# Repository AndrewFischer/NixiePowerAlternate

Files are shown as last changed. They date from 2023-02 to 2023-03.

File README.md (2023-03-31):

# NixiePowerAlternate
A regulated power supply for devices with a Nixie tube display.  
Vin is 9 to 14VDC.  Maximum input voltage is 16.5V. 
Outputs are 175VDC, 5VDC and 3.3VDC.<br>
MAX1771 maximum input is 16.5V which sets the upper limit on Vin.
TPS5430 and MAX1771 are inexpensive parts with reasonable performace. There are newer parts with better specs. Most are currently unavailable or beyond my ability to solder.
The TPS5430 is sensitive to choice of output capacitor. See the datasheet and application notes if you stray from the BOM.
#### Rev 0.1 Changes
* Improve HV boost regulator circuit.
* Correct footprint errors in Rev. 0. 
* Replace linear 5.0V regulator with a TPS5430 buck regulator.  Power the 3.3V regulator from the 5V supply. 

### Disclaimers and warnings
:exclamation: Danger of electric shock. 175Volts DC is present on this board.<br>
The files embodied in this repository are provided to you "as-is" and without warranty of any kind, express, implied or otherwise, including without limitation, any warranty of fitness for a particular purpose. See section 5 of the license.<br>
**This project is untested**.<br>
### License
[cc-by-nc 4.0](LICENSE.md)

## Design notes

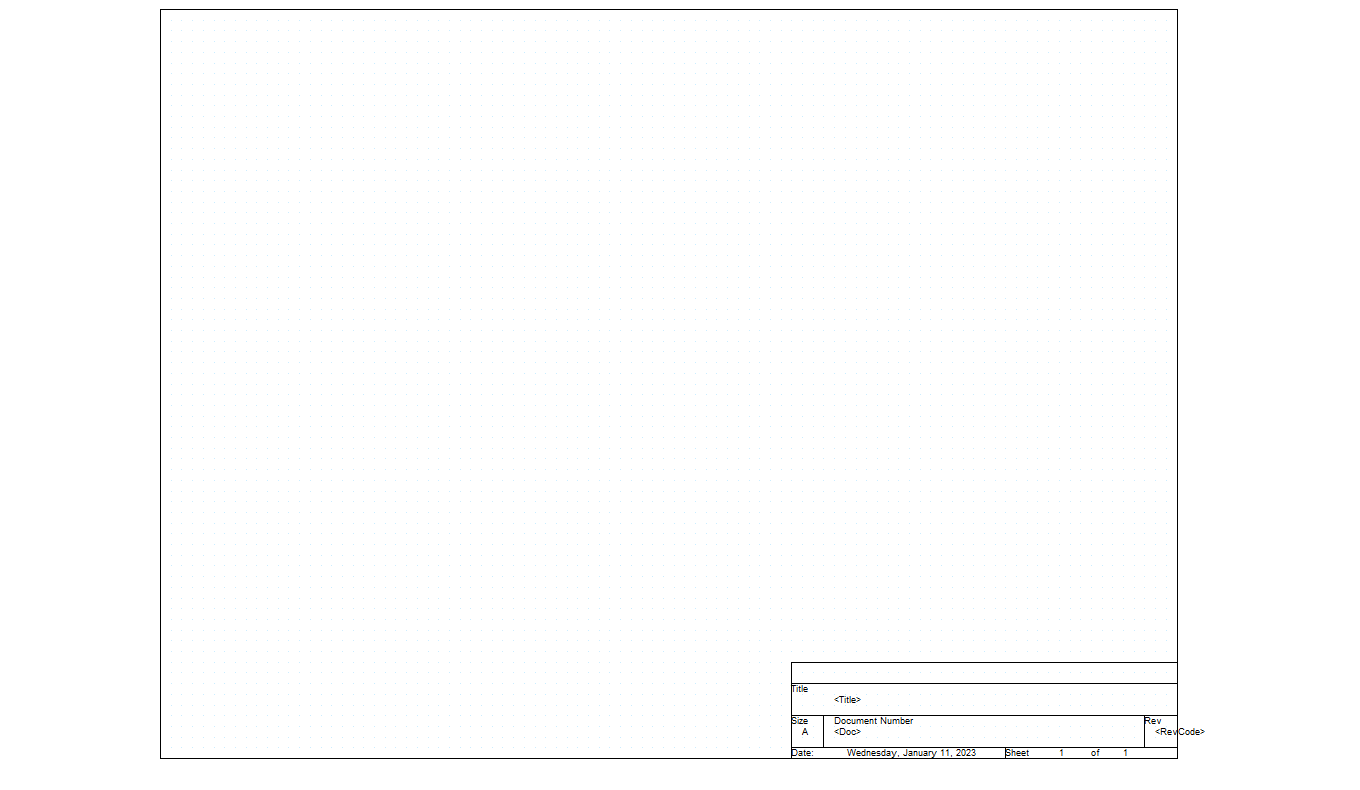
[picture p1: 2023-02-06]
NIXIEPOWERPSPICE.png

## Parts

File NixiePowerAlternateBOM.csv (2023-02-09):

Comment | Designator | Footprint | LCSC
4.7uF | C12,C13,C14 | Capacitor_SMD:C_1206_3216Metric_Pad1.33x1.80mm_HandSolder | C77094
100nF | C2,C5 | Capacitor_SMD:C_0805_2012Metric | C28233
47pF | C4 | Capacitor_SMD:C_1206_3216Metric_Pad1.33x1.80mm_HandSolder | C113890
1uF | C6 | Capacitor_SMD:C_0805_2012Metric_Pad1.18x1.45mm_HandSolder | C28323
100uF | C7,C9,C10,C11 | Capacitor_Tantalum_SMD:CP_EIA-3528-21_Kemet-B_Pad1.50x2.35mm_HandSolder | C16133
10nF | C8 | Capacitor_SMD:C_0805_2012Metric_Pad1.18x1.45mm_HandSolder | C1710
ES2F | D1 | Diode_SMD:D_SMB | C145321
SS34 | D2 | Diode_SMD:D_SMA_Handsoldering | C8678
~ | Q1 | Package_TO_SOT_SMD:TO-263-2 | C39238
1.18M | R1 | Resistor_SMD:R_1206_3216Metric_Pad1.30x1.75mm_HandSolder | C422598
0.05 | R2 | Resistor_SMD:R_1206_3216Metric_Pad1.30x1.75mm_HandSolder | C149662
10K | R3,R4 | Resistor_SMD:R_0805_2012Metric_Pad1.20x1.40mm_HandSolder | C17828
3.24K | R5 | Resistor_SMD:R_0805_2012Metric_Pad1.20x1.40mm_HandSolder | C245320
MAX1771ESA | U1 | Package_SO:SO-8_3.9x4.9mm_P1.27mm | C407903
AMS1117-3.3 | U2 | Package_TO_SOT_SMD:SOT-223-3_TabPin2 | C6186
TPS5430DDA | U3 | Package_SO:TI_SO-PowerPAD-8_ThermalVias | C9864

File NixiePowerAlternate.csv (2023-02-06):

Comment | Designator | Footprint | LCSC
100nF | C2,C3 | Capacitor_SMD:C_0805_2012Metric | C28233
1uF | C5,C6 | Capacitor_SMD:C_0805_2012Metric_Pad1.18x1.45mm_HandSolder | C28323
10uF | C7,C8 | Capacitor_Tantalum_SMD:CP_EIA-3216-18_Kemet-A | C7171
~ | D1 | Diode_SMD:D_SMB | C145321
~ | Q1 | Package_TO_SOT_SMD:TO-263-2 | C39238
0.05 | R1 | Resistor_SMD:R_1206_3216Metric_Pad1.30x1.75mm_HandSolder | C149662
1.2M | R2 | Resistor_SMD:R_1206_3216Metric_Pad1.30x1.75mm_HandSolder | C22107
6.8K | R3 | Resistor_SMD:R_0805_2012Metric_Pad1.20x1.40mm_HandSolder | C17772
AMS1117-5.0 | U1 | Package_TO_SOT_SMD:SOT-223-3_TabPin2 | C6187
MAX1771ESA | U2 | Package_SO:SO-8_3.9x4.9mm_P1.27mm | C407903
AMS1117-3.3 | U3 | Package_TO_SOT_SMD:SOT-223-3_TabPin2 | C6186

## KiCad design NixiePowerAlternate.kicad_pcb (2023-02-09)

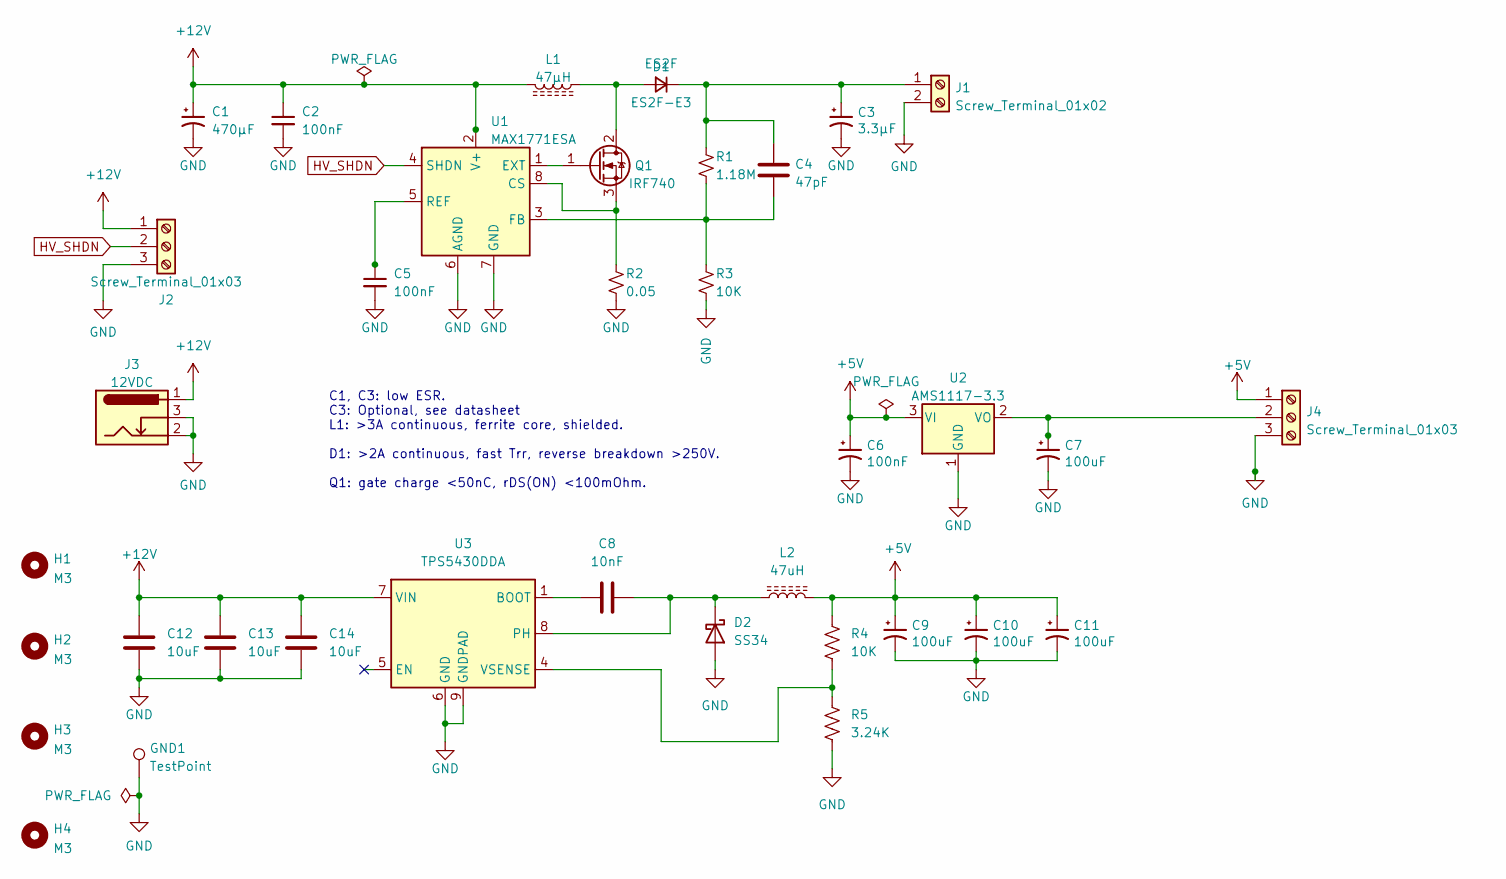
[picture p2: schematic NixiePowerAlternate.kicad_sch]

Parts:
C1: 470µF; CP_Radial_D10.0mm_P5.00mm; MPN UPW1V471MPD
C2, C5: 100nF; C_0805_2012Metric; Part# CL21B104KCFNNNE; LCSC C28233
C3: 3.3µF; CP_Radial_D10.0mm_P5.00mm; Part# UPW2G3R3MPD
C4: 47pF; C_1206_3216Metric_Pad1.33x1.80mm_HandSolder; MPN CC1206JRNPOBBN470; LCSC C113890
C6: 100nF; C_0805_2012Metric_Pad1.18x1.45mm_HandSolder; MPN CL21B104KBFNNNE; LCSC C28233
C7, C9, C10, C11: 100uF; CP_EIA-3528-21_Kemet-B_Pad1.50x2.35mm_HandSolder; MPN TAJB107K006RNJ; LCSC C16133
C8: 10nF; C_0805_2012Metric_Pad1.18x1.45mm_HandSolder; MPN CL21B103KBANNNC; LCSC C1710
C12, C13, C14: 10uF; C_1206_3216Metric_Pad1.33x1.80mm_HandSolder; MPN CL31A226KAHNNNE; LCSC C12891
D1: ES2F; D_SMB; MPN ES2F-E3; LCSC C145321
D2: SS34; D_SMA_Handsoldering; MPN SS34; LCSC C8678
GND1: TestPoint; TestPoint_THTPad_D4.0mm_Drill2.0mm
H1, H2, H3, H4: M3; MountingHole_3.2mm_M3
J1: Screw_Terminal_01x02; TerminalBlock_Phoenix_MKDS-1,5-2-5.08_1x02_P5.08mm_Horizont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
J2, J4: Screw_Terminal_01x03; TerminalBlock_Phoenix_MKDS-1,5-3-5.08_1x03_P5.08mm_Horizont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
J3: 12VDC; BarrelJack_RS_805-1696
L1: 47µH; L_CoilCraft_MSS1210; MPN MSS1210H-473ME
L2: 47uH; L_CoilCraft_MSS1048; MPN MSS1048-473MLB
Q1: TO-263-2; MPN IRF740; LCSC C39238
R1: 1.18M; R_1206_3216Metric_Pad1.30x1.75mm_HandSolder; Part# 1206W4F1184T5E; LCSC C422598
R2: 0.05; R_1206_3216Metric_Pad1.30x1.75mm_HandSolder; MPN CR1206FR050P05R; LCSC C149662
R3, R4: 10K; R_0805_2012Metric_Pad1.20x1.40mm_HandSolder; LCSC C17828
R5: 3.24K; R_0805_2012Metric_Pad1.20x1.40mm_HandSolder; MPN CR0805F3K24P05Z; LCSC C245320
U1: MAX1771ESA; SO-8_3.9x4.9mm_P1.27mm; LCSC C407903
U2: AMS1117-3.3; SOT-223-3_TabPin2; LCSC C6186
U3: TPS5430DDA; TI_SO-PowerPAD-8_ThermalVias; LCSC C9864

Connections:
+5V: C6.1, C9.1, C10.1, C11.1, J4.1, L2.2, R4.1, U2.3 (VI)
+12V: C1.1, C2.1, C12.1, C13.1, C14.1, J2.1, J3.1, L1.2, U1.2 (V+), U3.7 (VIN)
GND: C1.2, C2.2, C3.2, C5.2, C6.2, C7.2, C9.2, C10.2, C11.2, C12.2, C13.2, C14.2, D2.2 (A), GND1.1, J1.2, J2.3, J3.2, J3.3, J4.3, R2.2, R3.2, R5.2, U1.6 (AGND), U1.7 (GND), U2.1 (GND), U3.6 (GND), U3.9 (GNDPAD)
HV_SHDN: J2.2, U1.4 (SHDN)
unnamed: C3.1, C4.1, D1.1 (K), J1.1, R1.1
unnamed: C4.2, R1.2, R3.1, U1.3 (FB)
unnamed: C5.1, U1.5 (REF)
unnamed: C7.1, J4.2, U2.2 (VO)
unnamed: C8.1, U3.1 (BOOT)
unnamed: C8.2, D2.1 (K), L2.1, U3.8 (PH)
unnamed: D1.2 (A), L1.1, Q1.2 (D)
unnamed: Q1.1 (G), U1.1 (EXT)
unnamed: Q1.3 (S), R2.1, U1.8 (CS)
unnamed: R4.2, R5.1, U3.4 (VSENSE)

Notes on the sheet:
C1, C3: low ESR. C3: Optional, see datasheet L1: >3A continuous, ferrite core, shielded. D1: >2A continuous, fast Trr, reverse breakdown >250V. Q1: gate charge <50nC, rDS(ON) <100mOhm.

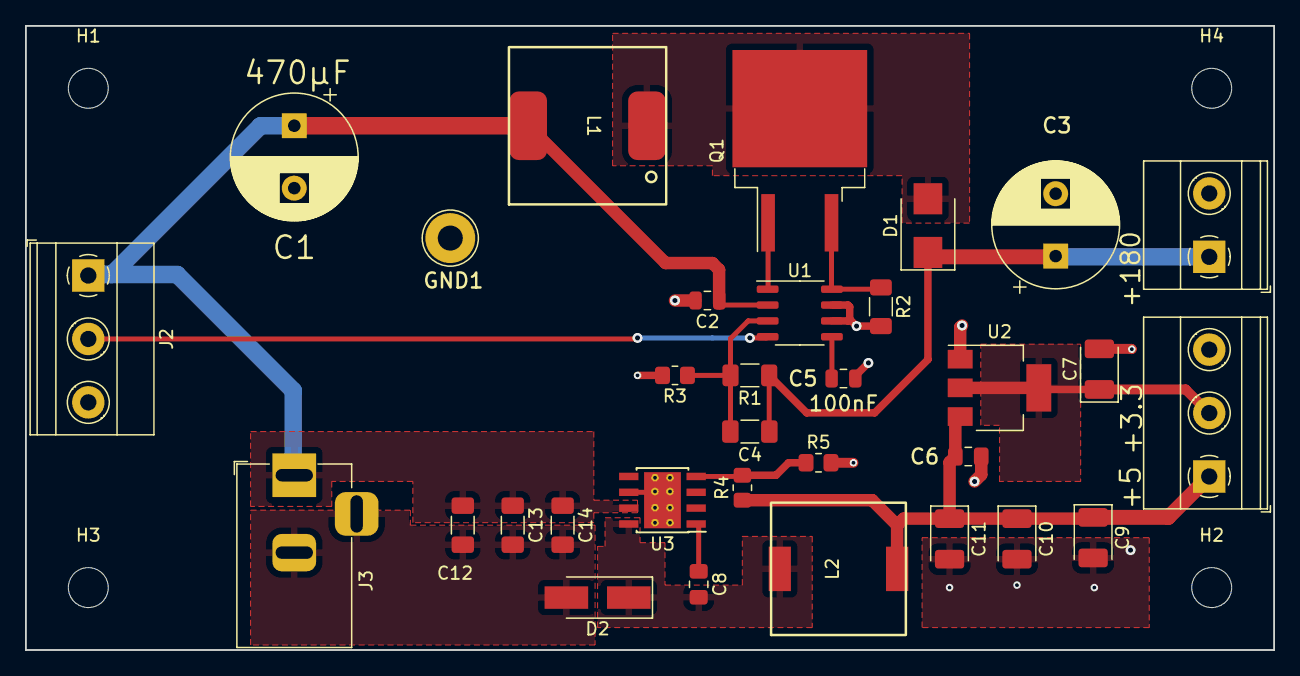
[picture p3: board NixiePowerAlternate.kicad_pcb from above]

Board: 2 copper layers, 100.0 x 50.0 mm, 36 parts (0 on the bottom side), 14 nets.

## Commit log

2023-02-06 Add files via upload
    Initial commit for Rev 0.
    Rev 0 has issues and should not be used as is.
    [DESIGN1.DSN, NIXIEPOWERPSPICE.DSN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]
2023-02-07 Add files via upload
    Checked L1 and Q1 against recommendations in the datasheet. Decided to keep as is. The MOSFET is fine. L1 should be too and it is rated for 400V.
    Added feed forward capacitor C9, 47pF in parallel with R2. The datasheet suggests values between 47pF and 220pF, using the lowest that insures stability. The design is stable in PSPICE without the cap. In practice it may be optional.
    Updated the PCB with the parts changes and fixed a layout error from Rev 0.
    [NixiePowerAlternate.kicad_pcb, NixiePowerAlternate.kicad_sch]
2023-02-08 Add files via upload
    Replace linear 5V regulator with a buck SMPS in the schematic.
    Begin adding MSS1048 footprint
    [NixiePowerAlternate.kicad_sch]
2023-02-09 Add files via upload
    Need to reduce cost before submitting for production.
    [NixiePowerAlternate.kicad_pcb, NixiePowerAlternate.kicad_sch, NixiePowerAlternateBOM.csv]
2023-02-09 Add files via upload
    Rev. 0.1 sent for fabriction. Ready to merge back into main.
    [NixiePowerAlternateBOM.csv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]
2023-02-21 Start converting to KiCad 7
    [NixiePowerAlternate.kicad_sch]
2023-02-21 Schematic cleanup
    Schematic now passes version 7 rules check.
    [NixiePowerAlternate.kicad_sch]
